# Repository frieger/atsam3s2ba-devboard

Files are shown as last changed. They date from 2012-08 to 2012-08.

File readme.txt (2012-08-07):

Cortex-M3 development platform

**********************************
* UNTESTED, USE AT YOUR OWN RISK *
**********************************
(PCBs sent off to fabrication)

Features:
- 5x5 cm size
- Provides breakout headers to almost all pins
- Provides crystal pads
- USB socket
- On-board usb-powered voltage regulator
- Low-cost I2C temperature sensor
- User LED
- 2 user switches
- Convenient Flash erase and reset switches

Components needed: (* denotes optional component, see description)
Ceramic chip capacitor, 0603, 100 nF                    10x*        C3, C4, C5, C6, C8, C9, C11, C12, C21, C22*
Ceramic chip capacitor, 0603, 2.2 uF                    6x          C1, C7, C10, C18, C19, C20
Ceramic chip capacitor, 0805, 10 uF                     1x          C2
Tantalum chip capacitor, Package C, 10 uF               1x          C17
Electrolytic capacitor, 100 uF, Panasonic EEUFR1C101H   1x          C12
Ceramic chip capacitor for crystals, 0603               4x*         C13*, C14*, C15, C16 (value see below)
LED, 0603                                               2x          D1, D2 (value see below)
Resistor for USB, 0603, 27R                             2x          R1, R2
Resistor for LED, 0603                                  2x          R3, R4 (value see below)
Resistor for I2C, 0603, 4.7k                            2x*         R5*, R6*
Watch crystal, 32KiHz, TC26                             1x*         X1, when using watch crystal, see product line
Crystal, 16 MHz, HC49                                   1x          X2
MCU, ATSAM3S2BA, TQFP-64                                1x          IC1
I2C Temp sensor, TCN75A, MSOP-8                         1x*         IC2
Pin header, 2x1                                         4x          Jumper headers USB, GND, 3.3V
Jumpers                                                 4x          Jumpers USB, GND, 3.3V
MCP1703-3.3 voltage regulator, SOT-223                  1x          U1
Push switch, 6x6mm, through-hole                        4x          Reset, Erase switch, 2 user switches
Mini-USB-B socket                                       1x          J1
Headers (male/female), 1x16                             2x          board edges
Headers (male/female), 1x18                             1x          board edges
Headers (male/female), 1x2                              1x*         when not using watch crystal, see product line

Product line (select either a.i or a.ii; optionally, select b):
(a.i) When using watch crystal:
      Populate X1, C13, C14
      Do not populate header near crystal
(a.ii) External ADC triggering/no watch crystal:
      Populate header near crystal
      Solder wires from crystal pad to header
      Do not populate X1, C13, C14
(b) Temperature sensor
      Populate IC2, R5, R6, C22
      I2C available on headers 36 (TWCK0) and 43 (TWD0)
      Software: Configure TWI0, Device address 1001000

MCU and USB socket are on the bottom side. Headers can be installed on the top or bottom side. 
Board can be mounted with 2 M3 screws. No insulation required.
Low-current LEDs recommended. Output voltage 3.3V

Capacitors for crystals
Parasitic capacitance currently unknown. Find out formula to calculate capacitor value.

LED resistors

calculation result
        current
voltage 5mA     10mA    15mA    20mA
1.8V    300     150     100     75
2.0V    260     130      87     65
2.5V    160      80      53     40
3.0V     60      30      20     15

real-world resistors (E12 series, 1%)
        current
voltage 5mA     10mA    15mA    20mA
1.8V    330     150     100     82
2.0V    270     120      82     68
2.5V    150      82      56     39
3.0V     68      33      22     15

Not recommended to run LEDs at 20 mA from the MCU. Low-current LEDs recommended.

USB resistors
TODO: Find out value of USB resistors from Atmel datasheet.
TODO: Find datasheet

SAM3S-EK development board user guide, p47 says 27R
SAM3S2-EK development board user guide, p47, says 27R

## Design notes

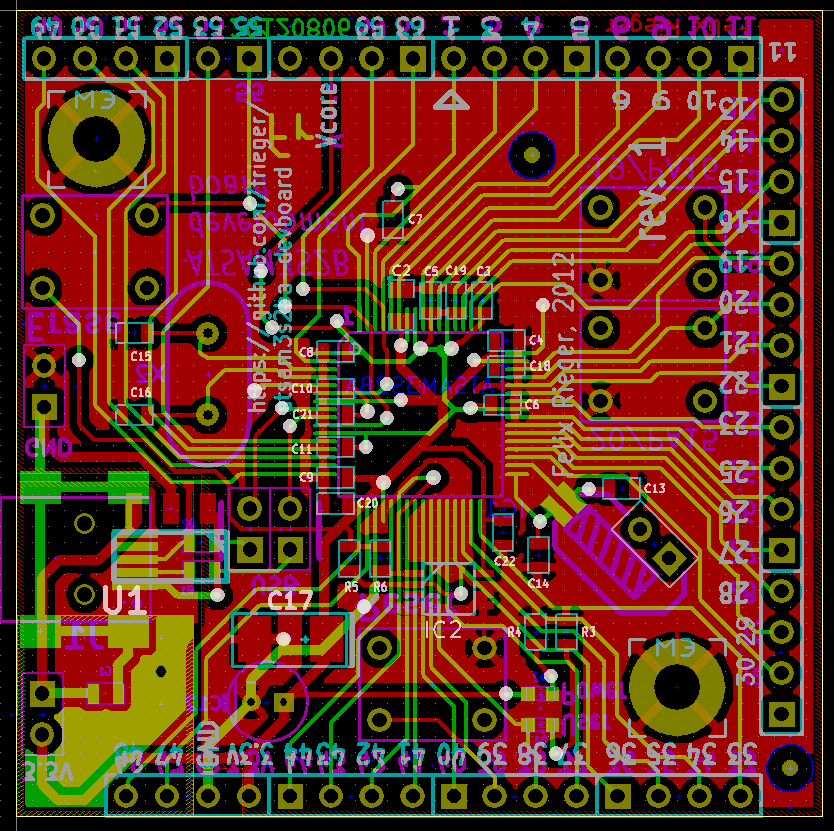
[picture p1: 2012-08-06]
img/board.png

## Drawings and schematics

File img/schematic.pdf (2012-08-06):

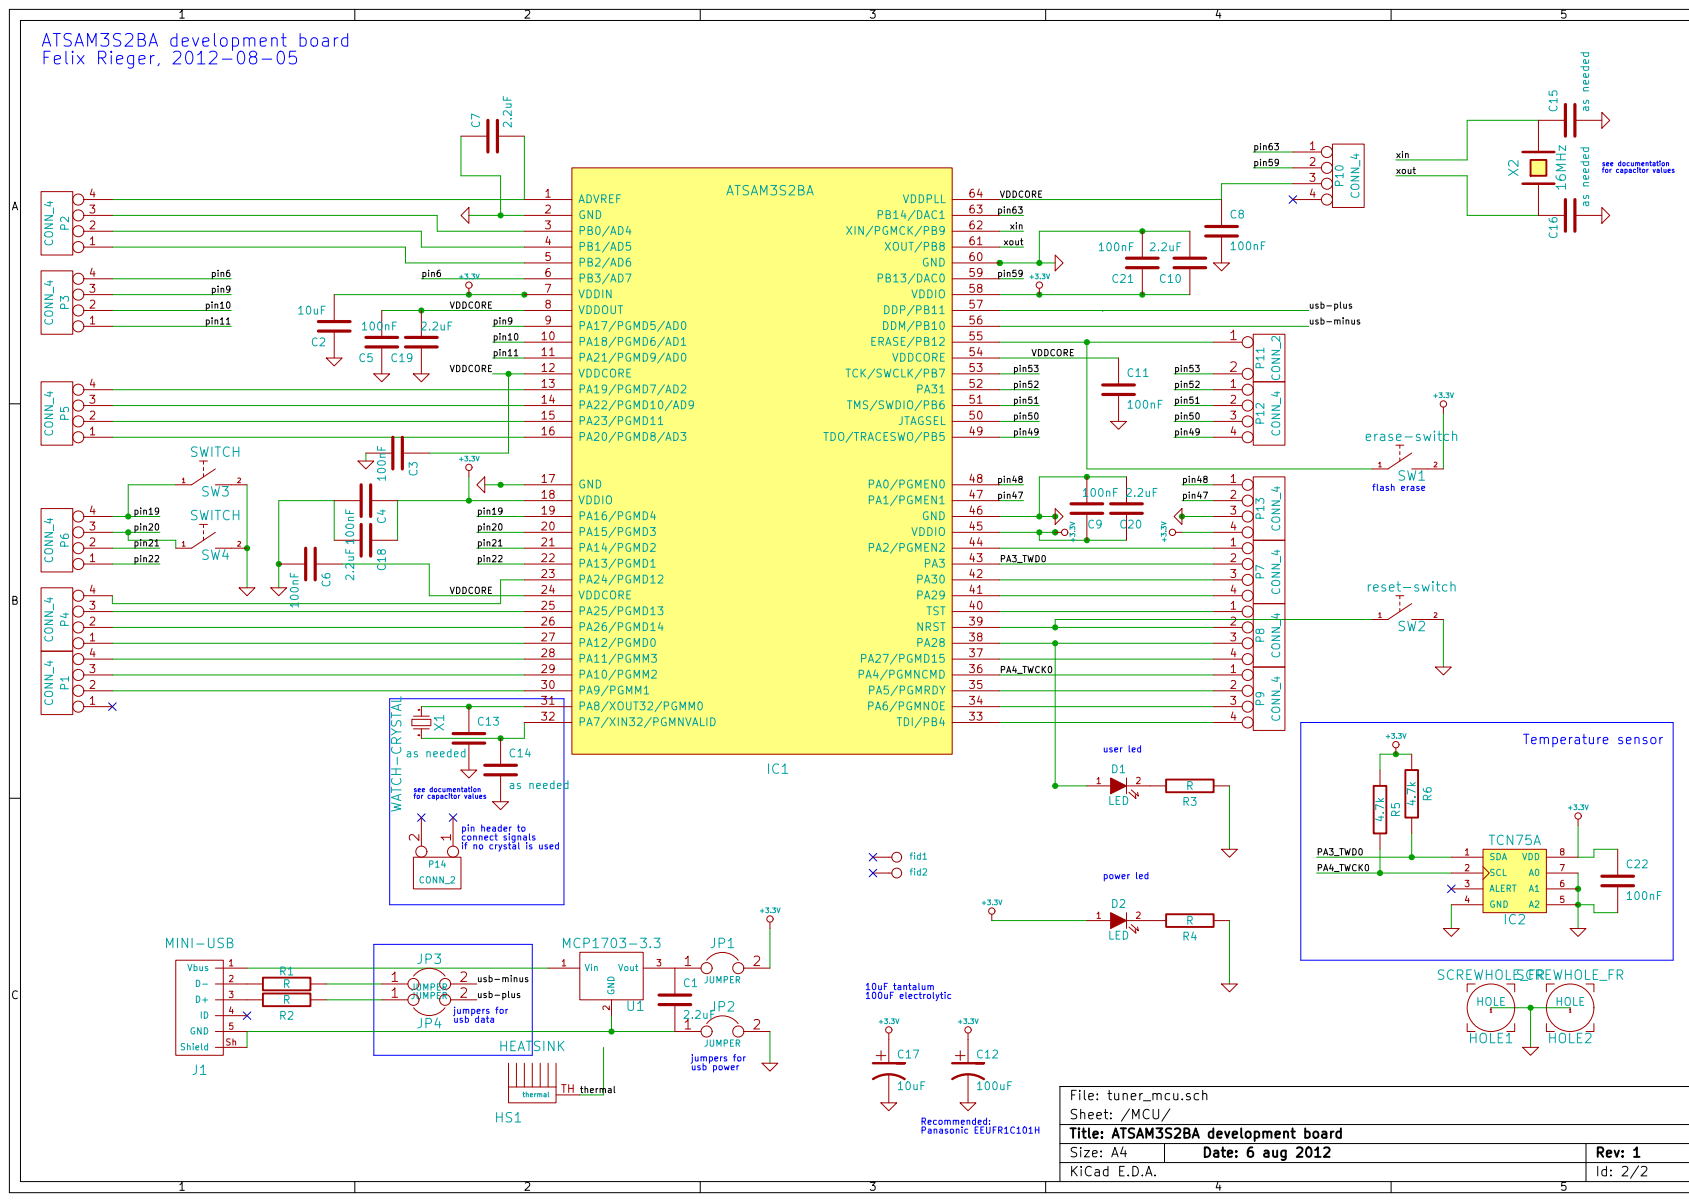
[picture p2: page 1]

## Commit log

2012-08-04 First commit: Development platform for ATSAM3S2BA - Schematics - Board - Readme with BOM
    [tuner.brd, tuner.sch, tuner_mcu.sch]
2012-08-04 Added temperature sensor Some additional refinements
    [tuner.brd, tuner.sch, tuner_mcu.sch]
2012-08-05 More text on board, component placement
    [tuner.brd]
2012-08-05 Documentation, Text on board
    [tuner.brd, tuner.sch, tuner_mcu.sch]
2012-08-05 adjusted placement of USB jumpers
    [tuner.brd]
2012-08-05 fabrication outputs
    [tuner-Back.gbl, tuner-Front.gtl, tuner-Mask_Back.gbs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]
2012-08-05 Board and schematic in human-readable formats
2012-08-06 Added 2 user switches
    [tuner.brd, tuner.sch, tuner_mcu.sch]
2012-08-07 Soldermask: Reduced global expansion, set to 0 at USB connector New fabrication files, sent off to prototype production
    [tuner.brd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]
